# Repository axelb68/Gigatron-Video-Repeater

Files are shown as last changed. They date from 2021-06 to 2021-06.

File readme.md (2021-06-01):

# Gigatron Video Repeater

The video repeater is a small add-on board for the Gigatron TTL computer (https://gigatron.io) to offload the task of duplicating video lines. Every first line out of four is written to an on-board memory and autonomously transmitted 4 times to the VGA output. By this the Gigatron can always be run in mode 3 and is still producing a screen output without blanked lines.

Main component is the asynchronous FIFO memory chip SN74ACT7201 (or compatible, see below) which is constructed with dual-port SRAM and internal write and read address counters. The read pointer can be reset independently of the write pointer for retransmitting previously read data.

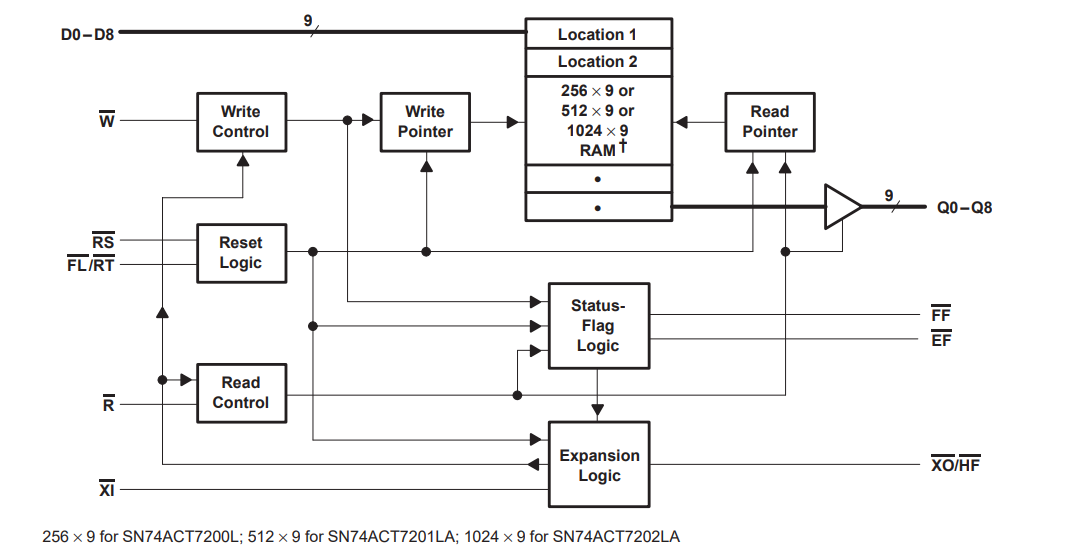
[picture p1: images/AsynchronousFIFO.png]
Working principle of the asynchronous FIFO memory chip


The first video line (out of four) writes each pixel to the memory which is followed by an immediate read. This is like a flow-through operation
which simply copies the pixel information back to the output.
A retransmit of the complete line is then performed for the next three HSYNC cycles.

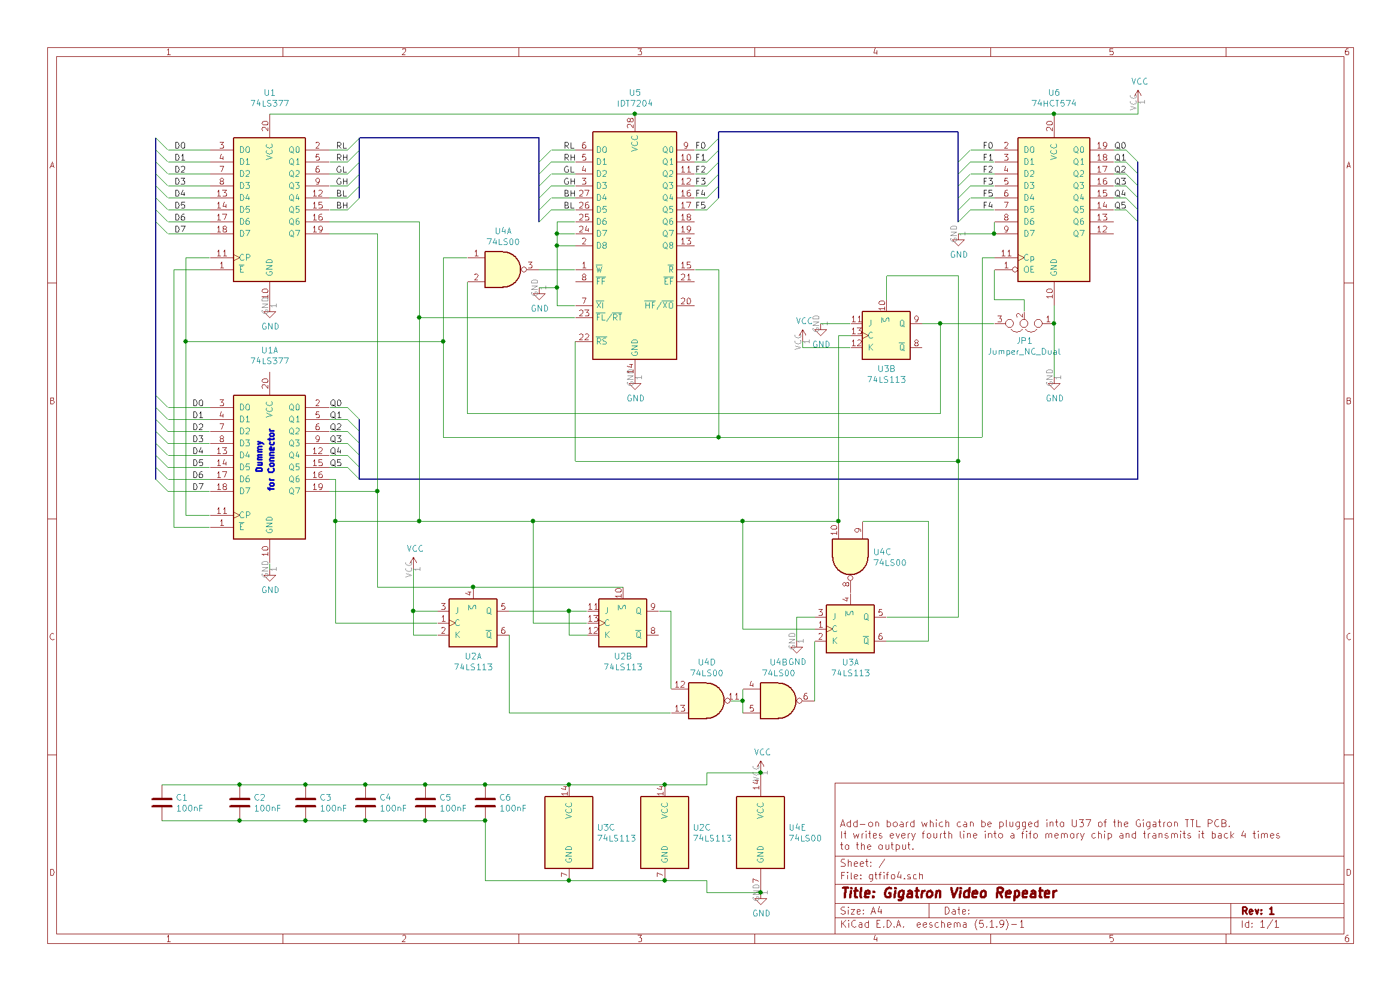
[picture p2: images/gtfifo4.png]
Video Repeater schematics


The schematics of the repeater shows connector U1A which can be plugged into the U37 output register socket of the Gigatron. HSYNC is divided by two JK flipflops (U2). The result is used to initialize the internal read and write pointers of the SN74ACT7201 to the first location. A 74HCT574 latches the memory output and passes it back to connector U1A for VGA output.
By means of a "scanlines on/off" jumper (JP1) the primary line can be blanked-out in order to create a "scanline look" similar to mode 1 of the Gigatron.

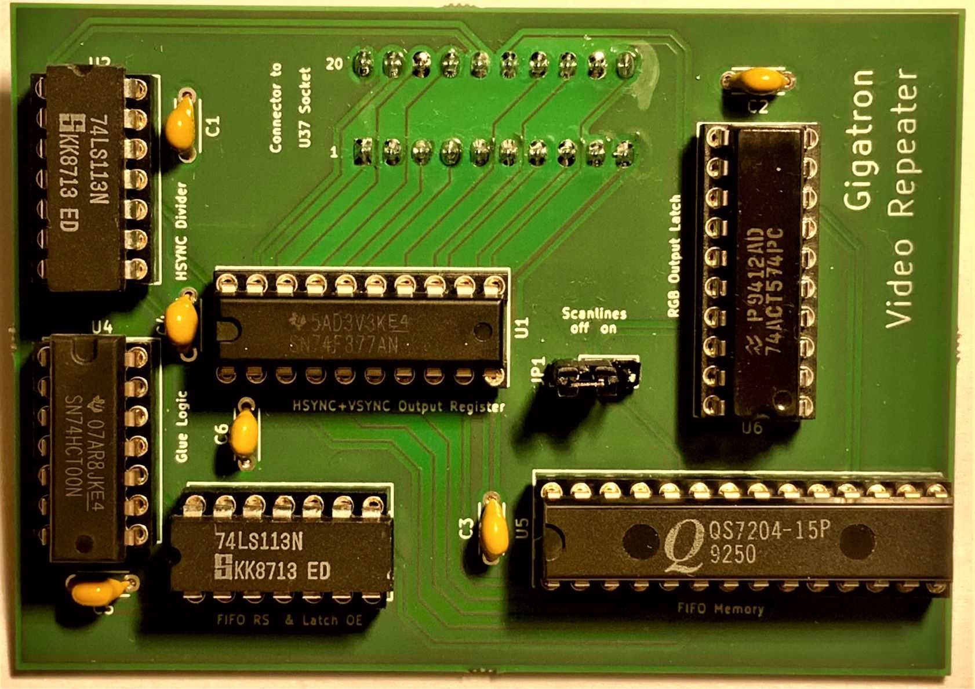
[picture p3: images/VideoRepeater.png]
Assembled repeater


So far I tested the board with different clones/extensions of the SN74ACT7201. IDT7201-15, IDT7202-25, and QS7204-15 worked fine.
The picture shows a mixture of 74F, 74ACT, and 74LS components which is not important, however. It is sufficient to use the HCT versions or even LS for the flipflops and the logic.

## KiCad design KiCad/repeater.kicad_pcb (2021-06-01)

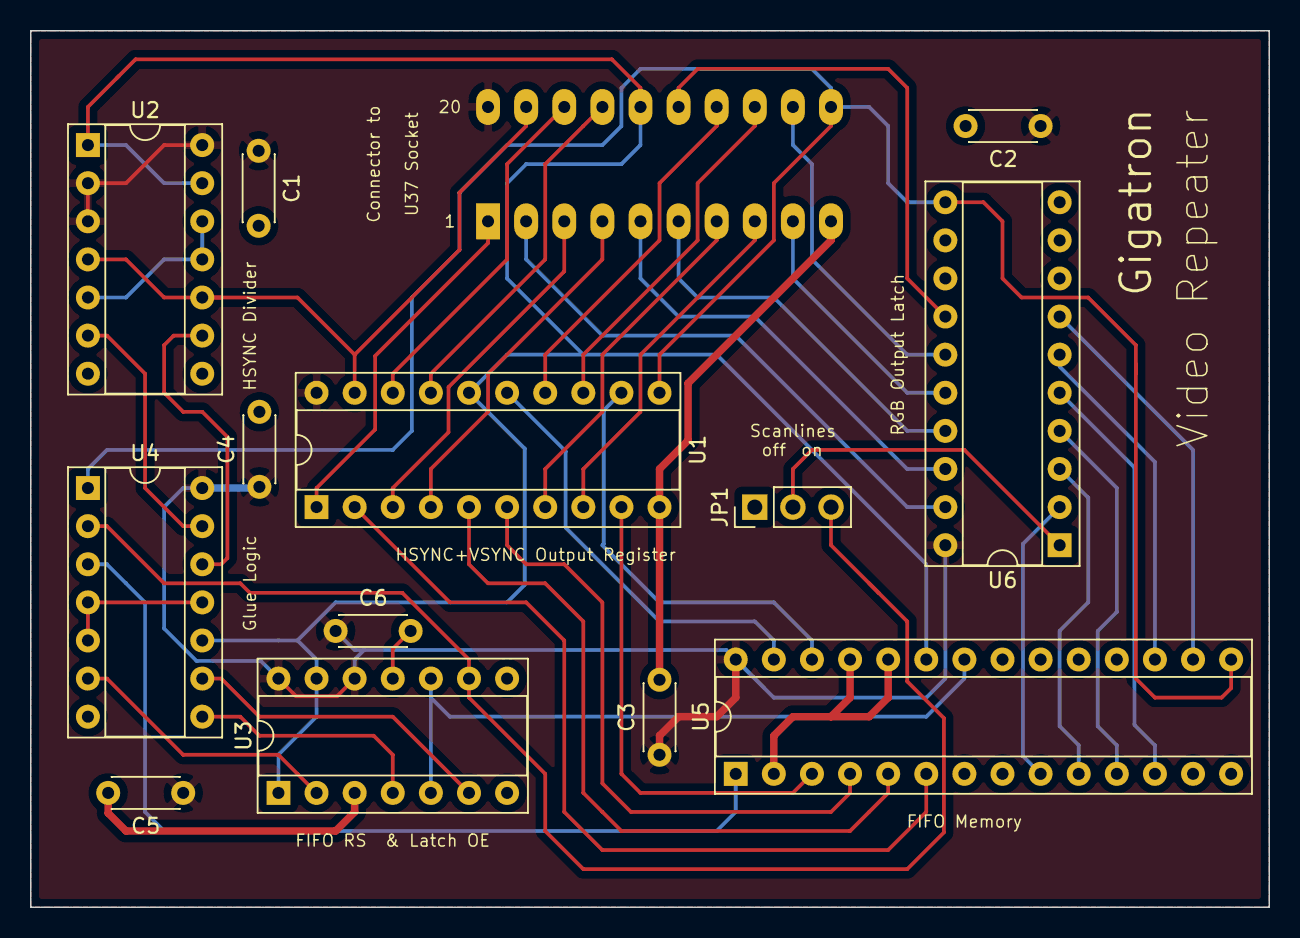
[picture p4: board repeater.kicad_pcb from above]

Board: 2 copper layers, 82.6 x 58.4 mm, 14 parts (0 on the bottom side), 43 nets.

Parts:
C1, C2, C3, C4, C5, C6: 100nF; C_Disc_D4.3mm_W1.9mm_P5.00mm
JP1: Jumper_NC_Dual; PinHeader_1x03_P2.54mm_Vertical
U1: 74HCT377; DIP-20_W7.62mm_Socket
U1A1: Connector; DIP-20_W7.62mm_Socket_LongPads
U2, U3: 74LS113; DIP-14_W7.62mm_Socket
U4: 74LS00; DIP-14_W7.62mm_Socket
U5: SN74ACT7201; DIP-28_W7.62mm_Socket
U6: 74HCT574; DIP-20_W7.62mm_Socket

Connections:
/BH: U1.15, U5.27
/BL: U1.12, U5.26
/D0: U1.3, U1A1.3
/D1: U1.4, U1A1.4
/D2: U1.7, U1A1.7
/D3: U1.8, U1A1.8
/D4: U1.13, U1A1.13
/D5: U1.14, U1A1.14
/D6: U1.17, U1A1.17
/D7: U1.18, U1A1.18
/F0: U5.9, U6.2
/F1: U5.10, U6.3
/F2: U5.11, U6.4
/F3: U5.12, U6.5
/F4: U5.16, U6.7
/F5: U5.17, U6.6
/GH: U1.9, U5.3
/GL: U1.6, U5.4
/Q0: U1A1.2, U6.19
/Q1: U1A1.5, U6.18
/Q2: U1A1.6, U6.17
/Q3: U1A1.9, U6.16
/Q4: U1A1.12, U6.15
/Q5: U1A1.15, U6.14
/RH: U1.5, U5.5
/RL: U1.2, U5.6
GND: C1.2, C2.2, C3.2, C4.2, C5.2, C6.2, JP1.1, U1.10, U1A1.10, U2.7, U3.3, U3.7, U3.11, U4.7, U5.2, U5.7, U5.14, U5.24, U5.25, U6.8, U6.9, U6.10
unnamed: JP1.2, U6.1
unnamed: JP1.3, U3.9, U4.2
unnamed: U1.1, U1A1.1
unnamed: U1.11, U1A1.11, U4.1, U5.15, U6.11
unnamed: U1.16, U1A1.16, U2.1, U2.13, U3.1, U3.13, U4.10, U5.23
unnamed: U1.19, U1A1.19, U2.4, U2.10
unnamed: U2.6, U4.13
unnamed: U2.9, U4.12
unnamed: U2.5, U2.11, U2.12
unnamed: U3.2, U4.6
unnamed: U3.4, U4.8
unnamed: U3.6, U4.9
unnamed: U3.5, U3.10, U5.22
unnamed: U4.3, U5.1
unnamed: U4.4, U4.5, U4.11
VCC: C1.1, C2.1, C3.1, C4.1, C5.1, C6.1, U1.20, U1A1.20, U2.2, U2.3, U2.14, U3.12, U3.14, U4.14, U5.28, U6.20
